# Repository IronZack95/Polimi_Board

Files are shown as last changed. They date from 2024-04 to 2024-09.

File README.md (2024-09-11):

# Polimi_Board
Design of new board for **Politecnico di Milano** Univeristy. \
This project is for the Embedded Systems course.
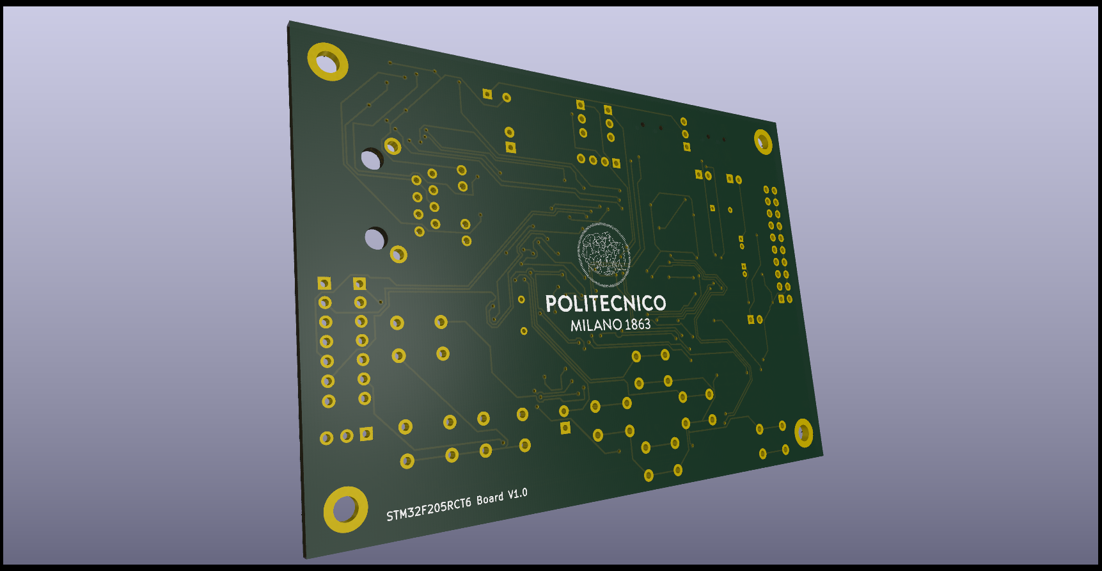
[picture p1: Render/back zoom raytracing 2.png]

## Description
The board is based on *STM32* chip - **[STM32F205RCT6](https://www.st.com/resource/en/datasheet/stm32f205rb.pdf)** as a main core.
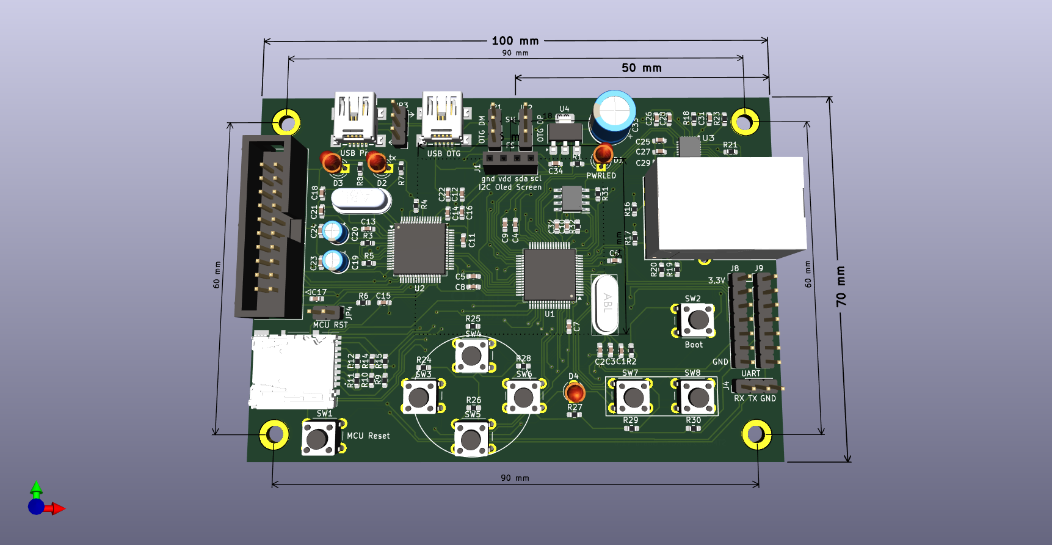
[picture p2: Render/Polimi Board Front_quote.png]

# Board Design specifications
- [x] 1x [specific main core chip](https://estore.st.com/en/stm32f205rct6-cpn.html)
- [x] 1x micro-USB B Port, directly connencted to the main chip.
- [x] 1x micro-USB B Port, for serial progeamming chip **FT2232**
- [x] 1x micro-SD Port, With SDIO/MMC protocol
- [x] 1x Ethernet Port, with magnetic transformer included, wired to **LAN8742** chip
- [x] 1x reset button
- [x] 6x General buttons, 4 of them placed as a joystick cross, the others beside
- [x] 1x power LED
- [x] 1x JTAG interface
- [x] 1x LED linked to a GPIO Port
- [x] 1x [OLED SCREEN I2C AMAZON](https://www.amazon.it/AZDelivery-Display-retroilluminato-Raspberry-gratuito/dp/B078J78R45?ref_=ast_sto_dp&th=1), or [OLED SCREEN I2C AZ-DELIVERY](https://www.az-delivery.de/it/products/1-3zoll-i2c-oled-display)
- [x] 1x External Flash SPI chip

# Notes
- Jumpers are introduced to choose the direction of the USB OTG, in one case HS (High speed) and in one case FS (Full speed)
- Jumpers are introduced to choose power from USB OTG and USB Programming
- The primary source of power arrives from USB
- Board size **10cm x 7cm**
- Hole distances **6cm x 9cm**

## BOM - Mouser
https://www.mouser.it/api/CrossDomain/GetContext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

# Potential problems
- cambiati i simboli dei connettori RJ45, micro SD e mini USB
- la micro SD non ha l'uscita WRITE PROTECT, è un problema? è stata scollegata 
- microSD card detect è stato messo in corrispondenza di PC6 -> SDIO_D6

# To be reviwed
 - [x] La footprint del cristallo da 25 MHz è sbagliata, la distanza tra i pin è 4.15mm invece che 4.88. Dovrebbe essere uguale a quella del cristallo da 12 MHz che invece è giusta.
- [x] Puoi togliere dalla BOM l'STM32 perché li abbiamo già in abbondanza
- [x] Per i led si può scendere col prezzo: ad esempio un led verde da 0.15$ invece che 0.3: https://www.mouser.it/ProductDetail/Wurth-Elektronik/151031VS06000?qs=LlUlMxKIyB01ggED1iKswA%3D%3D
- [x] Idem per i condensatori; questi da 100nF (0.1uF) costano solo 0.093€ l'uno: https://www.mouser.it/ProductDetail/KYOCERA-AVX/06033G104ZAT2A?qs=NXubJDmysXJMPmHfVo6Z%252BA%3D%3D
Ricorda di ordinare per prezzo (e filtra solo per i componenti in stock al momento) quando cerchi i componenti e specialmente per i passivi prendi sempre le cose meno costose (finchè sono in specifica per quanto riguarda voltaggio (potenza per le resistenze) e valore del componente).
In generale tutti i passivi mi sembrano più costosi del necessario.
- [x] Condensatore da 47uF: hai scelto un condensatore ai polimeri, costano ma a parte che non hanno la tendenza di sputare fuori l'elettrolita hanno caratteristiche generalmente *peggiori* dei condensatori elettrolitici normali. Per gli elettrolitici è preferibile prendere quelli through hole "vecchio stile", con una tensione di lavoro/temperatura massima sovradimensionata. Per esempio questi condensatori da 47uF della Panasonic https://www.mouser.it/ProductDetail/Panasonic/EEU-EB1J470S?qs=ctSfcQVnnmTBOdyC1HlWZw%3D%3D non costano nulla (0.26€ cadauno) e hanno una durata di esercizio di ben 5000 ore e una tensione max di lavoro di 63V e una temperatura massima di 105°C. Nella nostra applicazione è perfettamente equivalente al condensatore ai polimeri (anzi l'unica differenza sostanziale è che il condensatore ai polimeri andava fino a 100V, cosa che non ci serve) ma costa 1/10 del prezzo.
- [x] i chip vanno bene, i connettori vanno bene, riguarda tutti i passivi e cerca di scendere coi prezzi. Ho guardato principalmente i condensatori ma non escludo che si possa scendere di prezzo anche con le resistenze.
- [x] Mi sembra che manca il connettore IDC per il JTAG e le strip da 2.54mm per jumper e breakout vari. Il connettore IDC lo possiamo lasciare fuori dalla BOM perché non credo ci servirà e i connettori costano.
- [x] Per le strip da 2.54mm ti consiglio questa serie: https://www.mouser.it/c/?tradename=EconoStik Attenzione a selezionare nel filtro le seguenti proprietà, altrimenti le misure del connettore saranno sbagliate:
- Termination Post Length: 3.05mm
- Mating Post Length: 5.84mm

Commenti vari sul layout:
- [x] I connettori USB posizionali bene in modo che l'estremità del connettore (quella suggerita dal silkscreen) arrivi a toccare il bordo della scheda, altrimenti non sarà possibile infilare la spina nel connettore senza che il corpo della spina ostruisca l'inserimento.
- [x] Idem come sopra per il connettore Ethernet. Le sagome di ingombro della libreria di KiCad (quelle che compaiono col bordo rosa) sono estremamente conservative; non farti problemi a farle intersecare un po' se lo ritieni necessario.
- [x] Le dimensioni della scheda sembrano un po' abbondanti, magari si può scorciare un pochino verticalmente (tipo 60mmx100mm invece che 100x100)

## Usefull Links
- [Big Board reference with Ram](https://github.com/HEAPLab/marco-ram-board/tree/master)
- [Thermal camera project](https://github.com/fedetft/thermal_camera)
- [How to connect micro SD](https://emanbuc.gitbooks.io/appunti-iot/content/manuscript/sd_card_connection.html)
- [Oled alternatives](https://www.az-delivery.de/it/products/0-96zolldisplay), or [like](https://www.ebay.it/itm/204428760352?itmmeta=01HQXT2FC1579AP9QA0BS3KWXZ&hash=item2f98e75520:g:HqMAAOSw8oZhO3MO) (NOT USED!!)

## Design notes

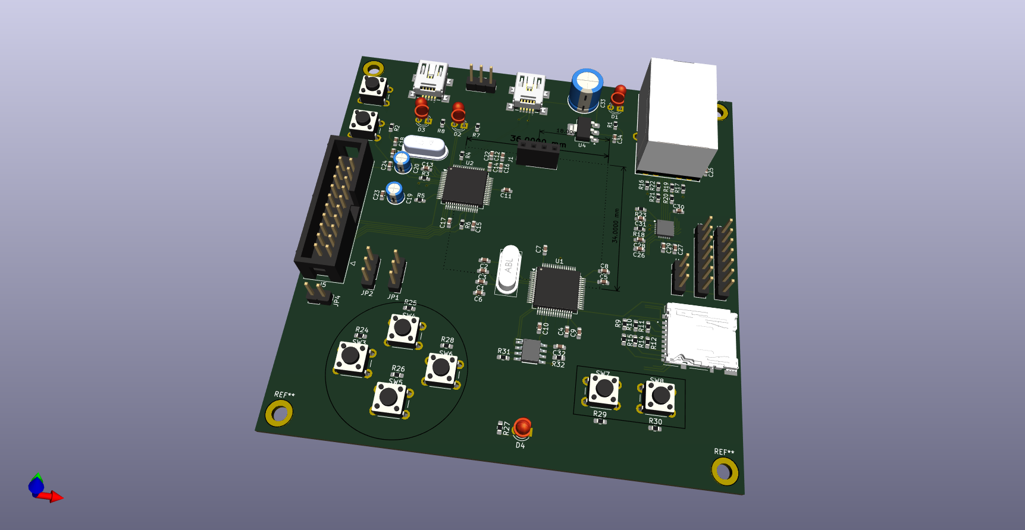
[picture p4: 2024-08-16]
Polimi Board.png

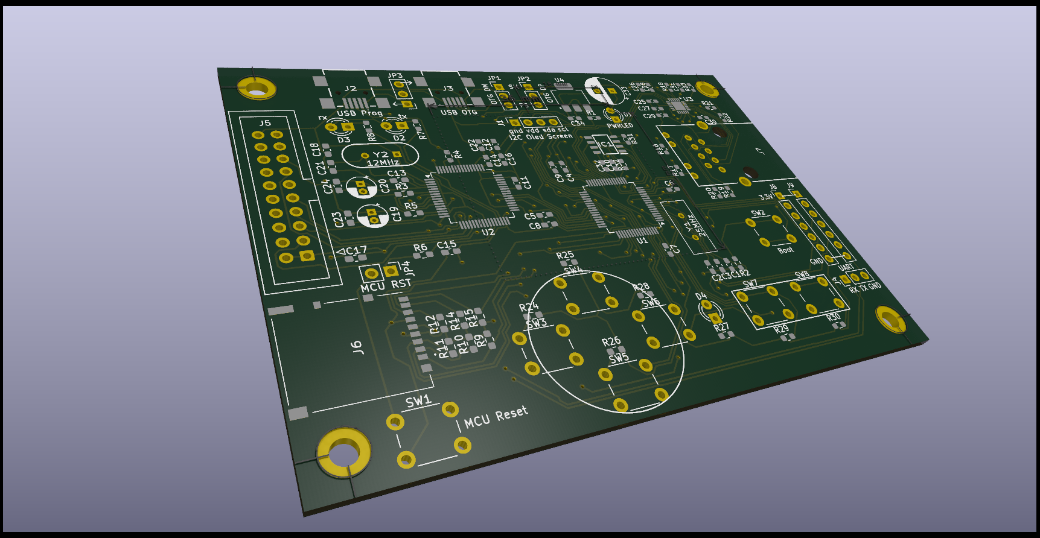
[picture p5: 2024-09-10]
Render/front raytracing 2.png

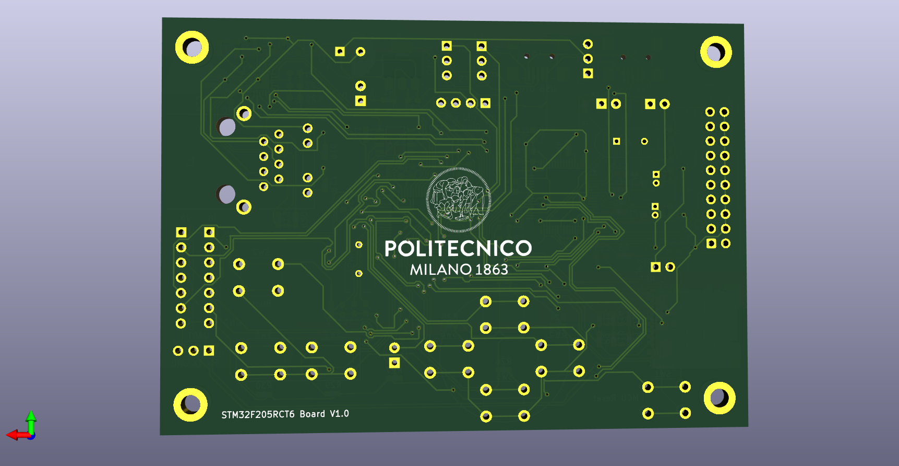
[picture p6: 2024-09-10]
Render/Polimi Board Back.png

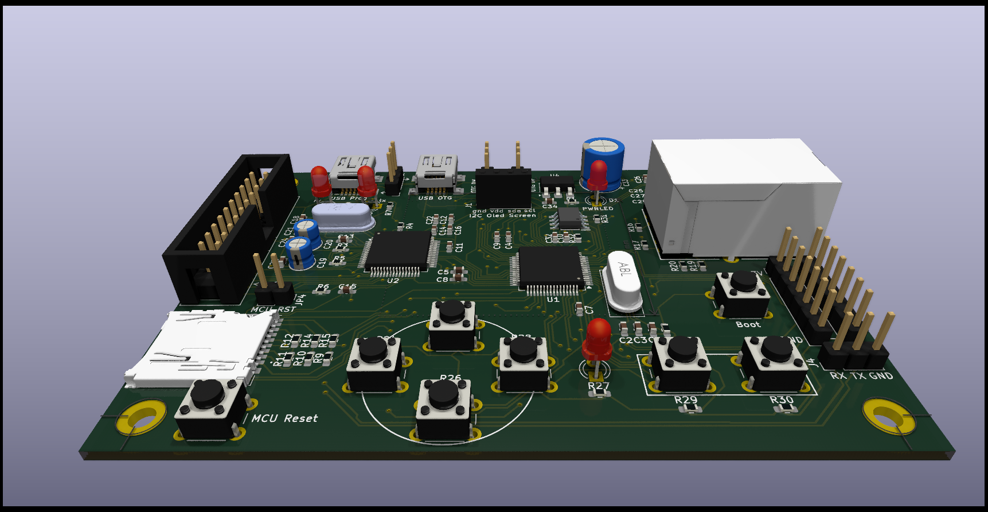
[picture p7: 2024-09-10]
Render/front raytracing.png

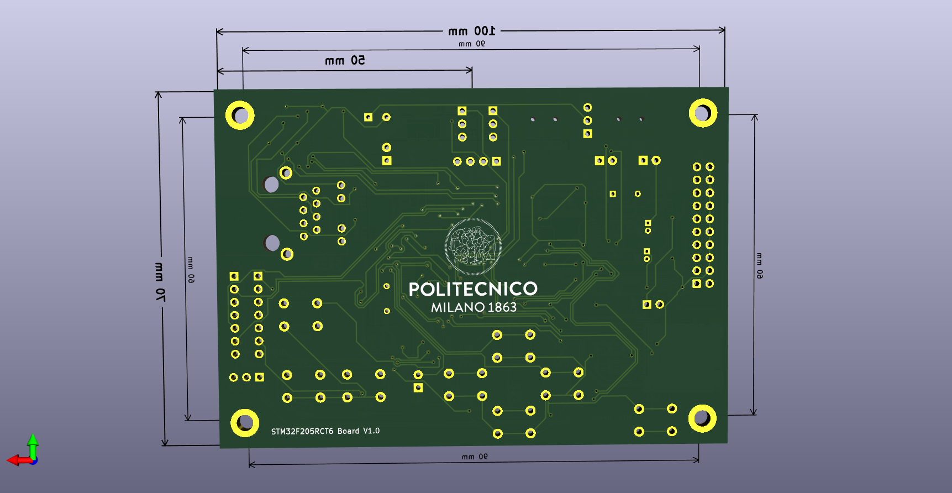
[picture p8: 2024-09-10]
Render/Polimi Board Back_quote.png

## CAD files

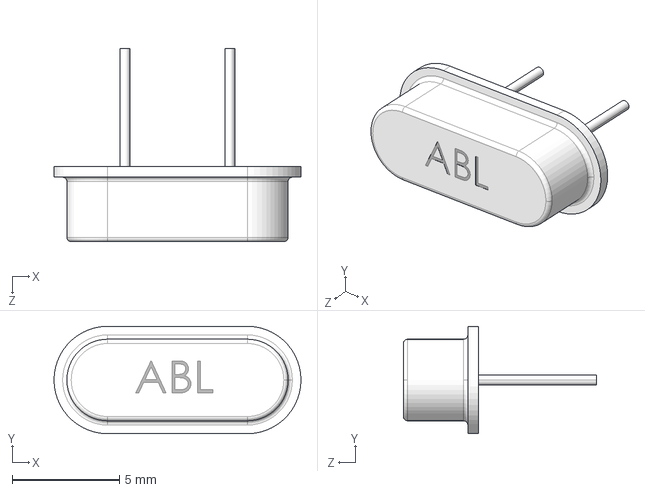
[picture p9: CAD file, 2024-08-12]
Imported/LIB_ABL-25.000MHz-B1UB/ABL-25.000MHz-B1UB/3D/ABL-25.000MHz-B1UB.stp
11.5 x 5.00 x 9.00 mm

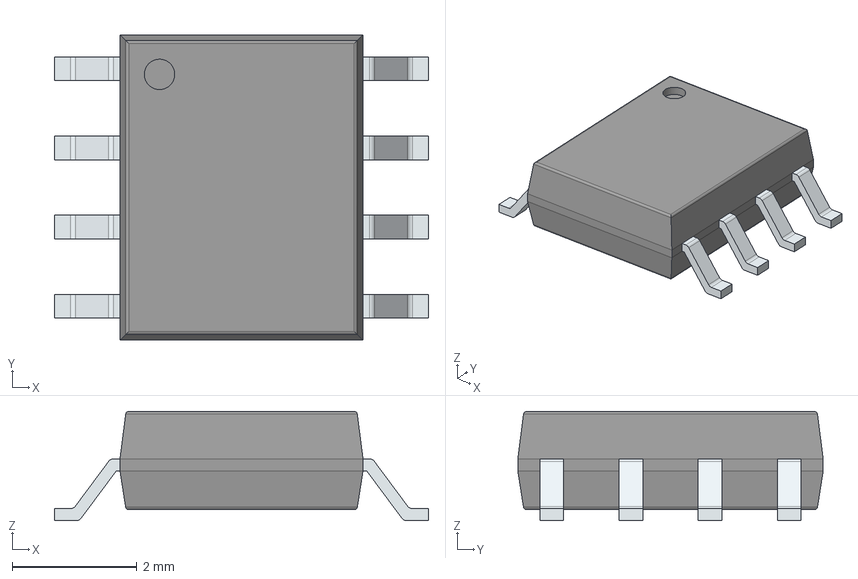
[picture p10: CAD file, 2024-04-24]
Imported/LIB_M95512-RMN6P/M95512-RMN6P/3D/M95512-RMN6P.stp
6.00 x 4.90 x 1.75 mm
PinsArrayLR

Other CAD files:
Imported/LIB_ABL-25.000MHz-B1UB/ABL-25.000MHz-B1UB/Allegro/abl25000mhzb1ub.psm
Imported/LIB_ABL-25.000MHz-B1UB/ABL-25.000MHz-B1UB/DEHDL/abl_25.000mhz_b1ub/chips/chips.prt
Imported/LIB_M95512-RMN6P/M95512-RMN6P/Allegro/soic127p600x175-8n.psm
Imported/LIB_M95512-RMN6P/M95512-RMN6P/DEHDL/m95512_rmn6p/chips/chips.prt

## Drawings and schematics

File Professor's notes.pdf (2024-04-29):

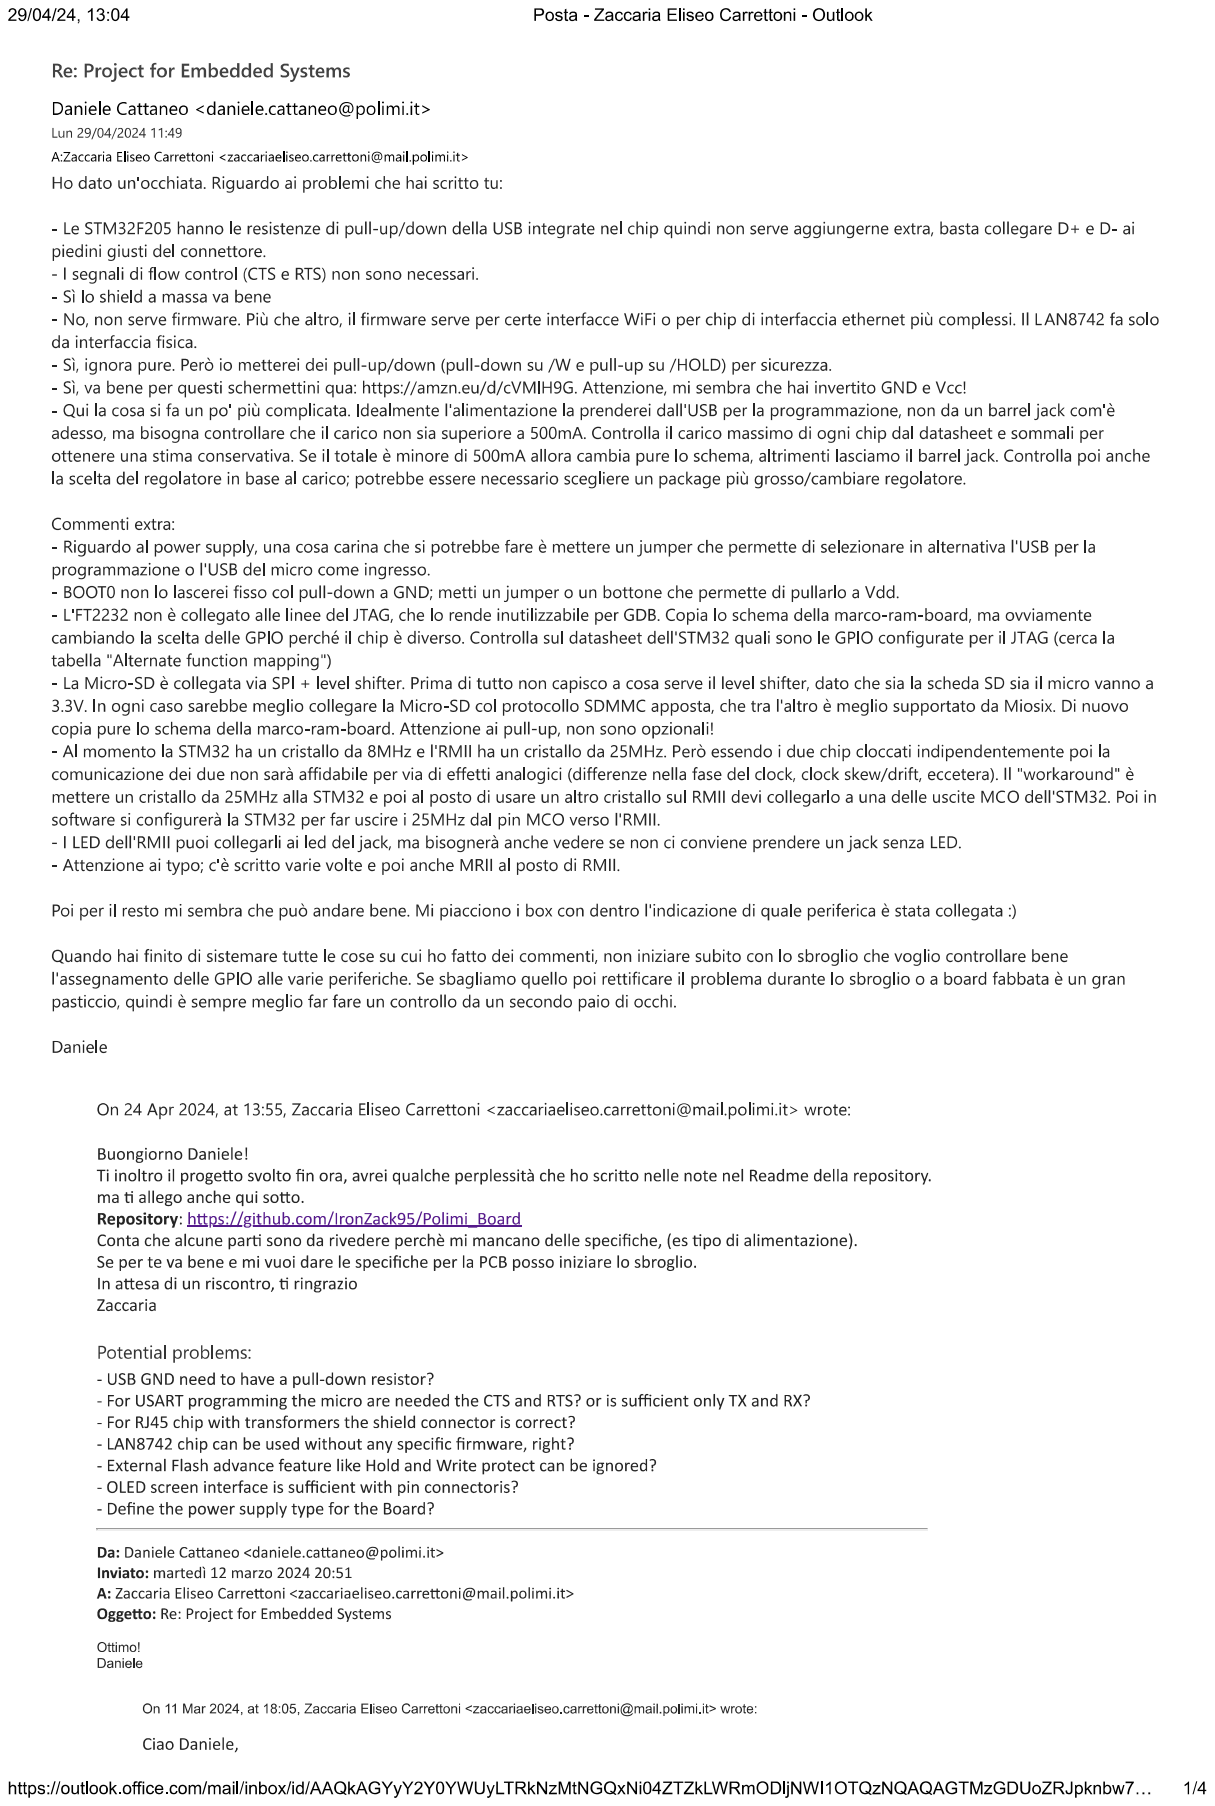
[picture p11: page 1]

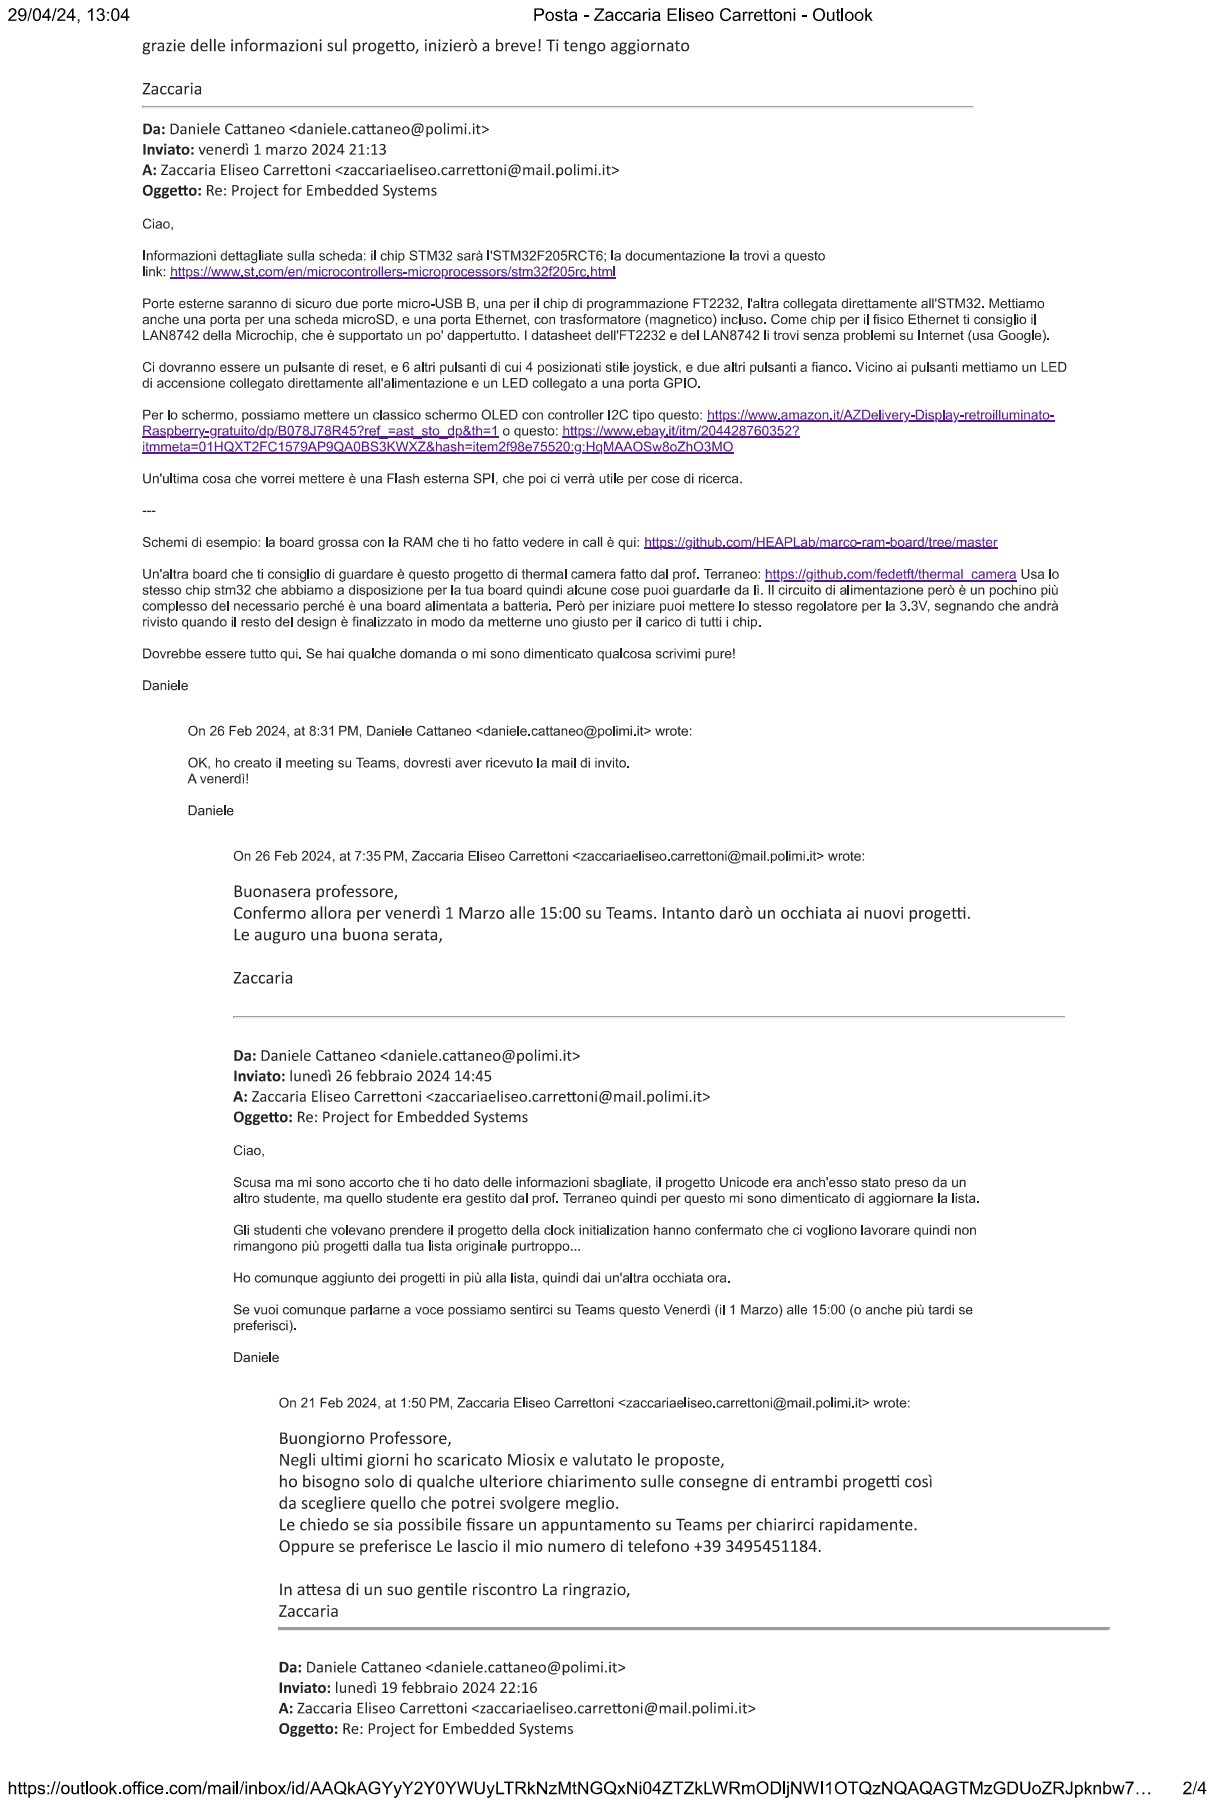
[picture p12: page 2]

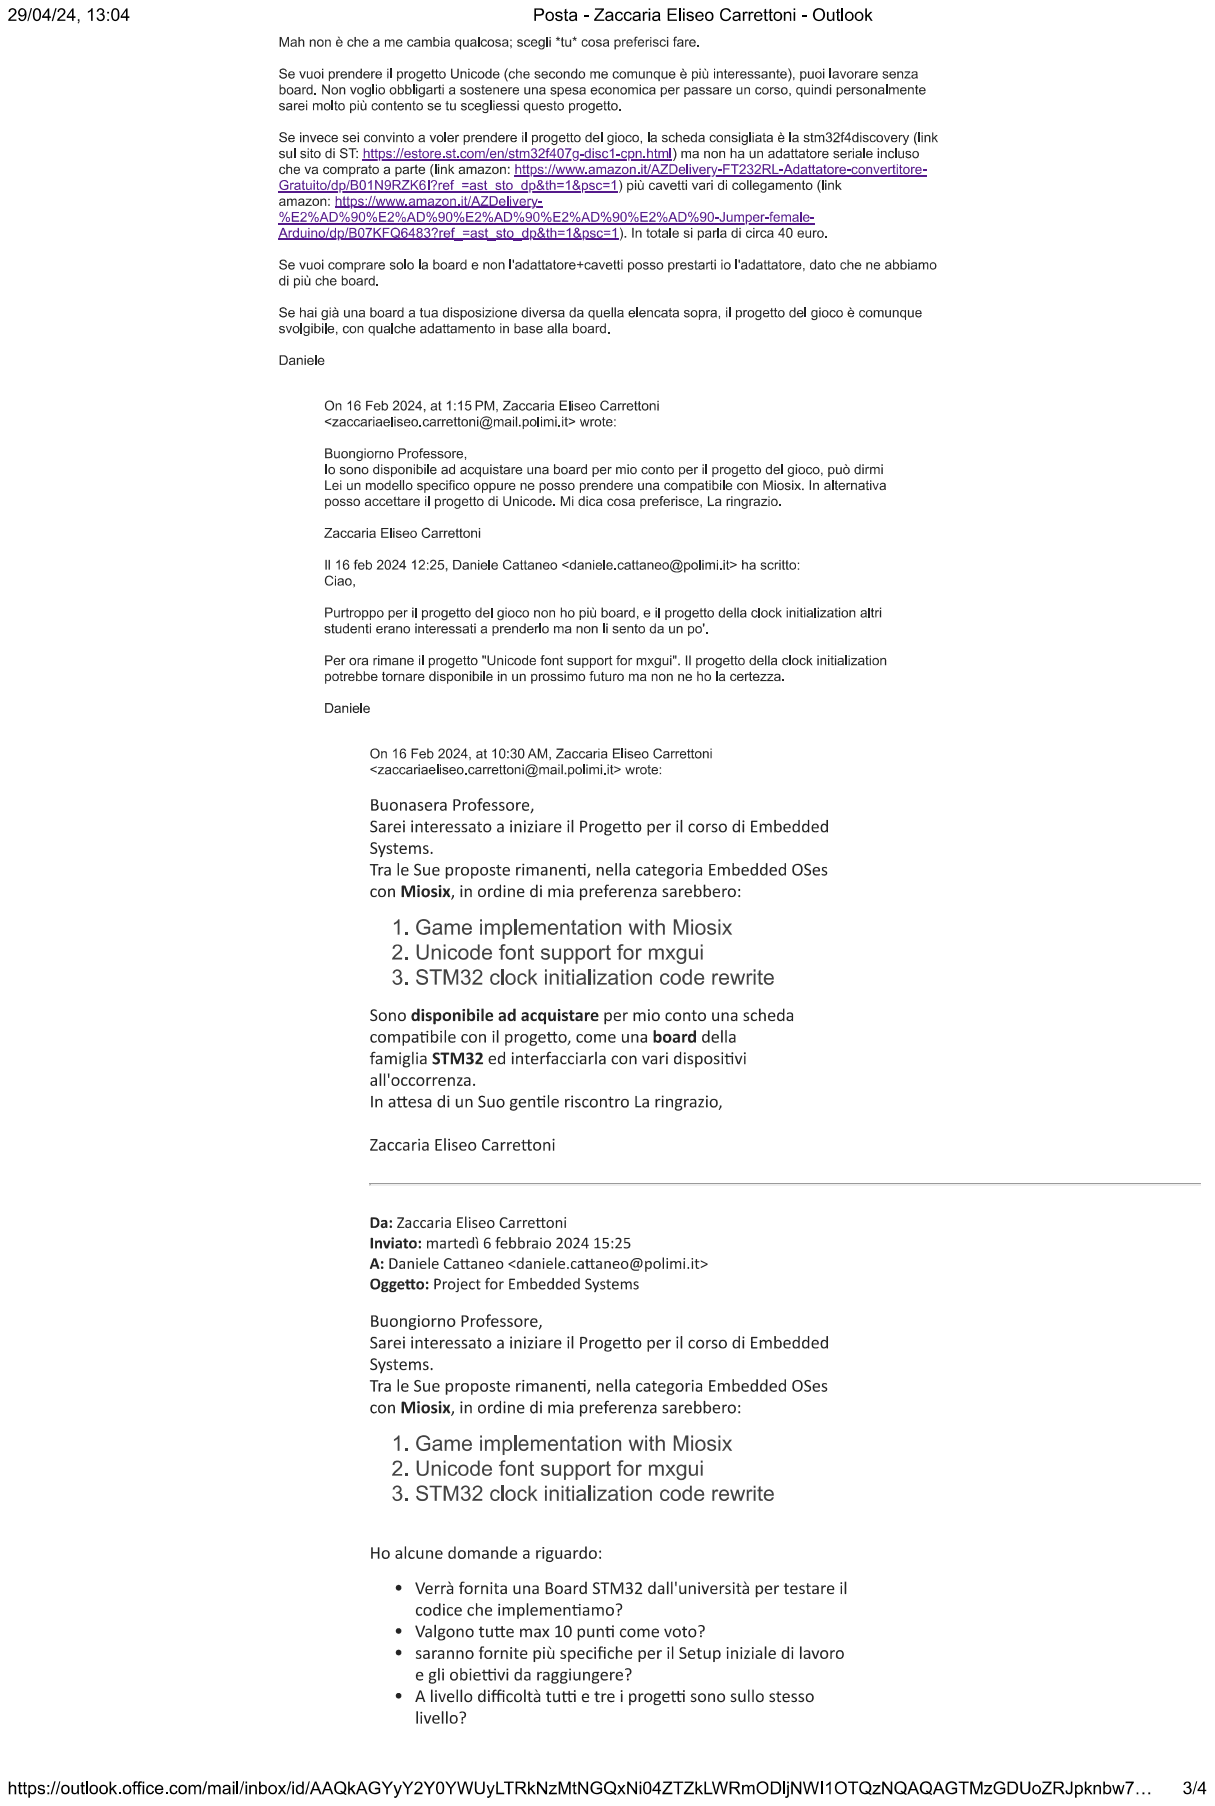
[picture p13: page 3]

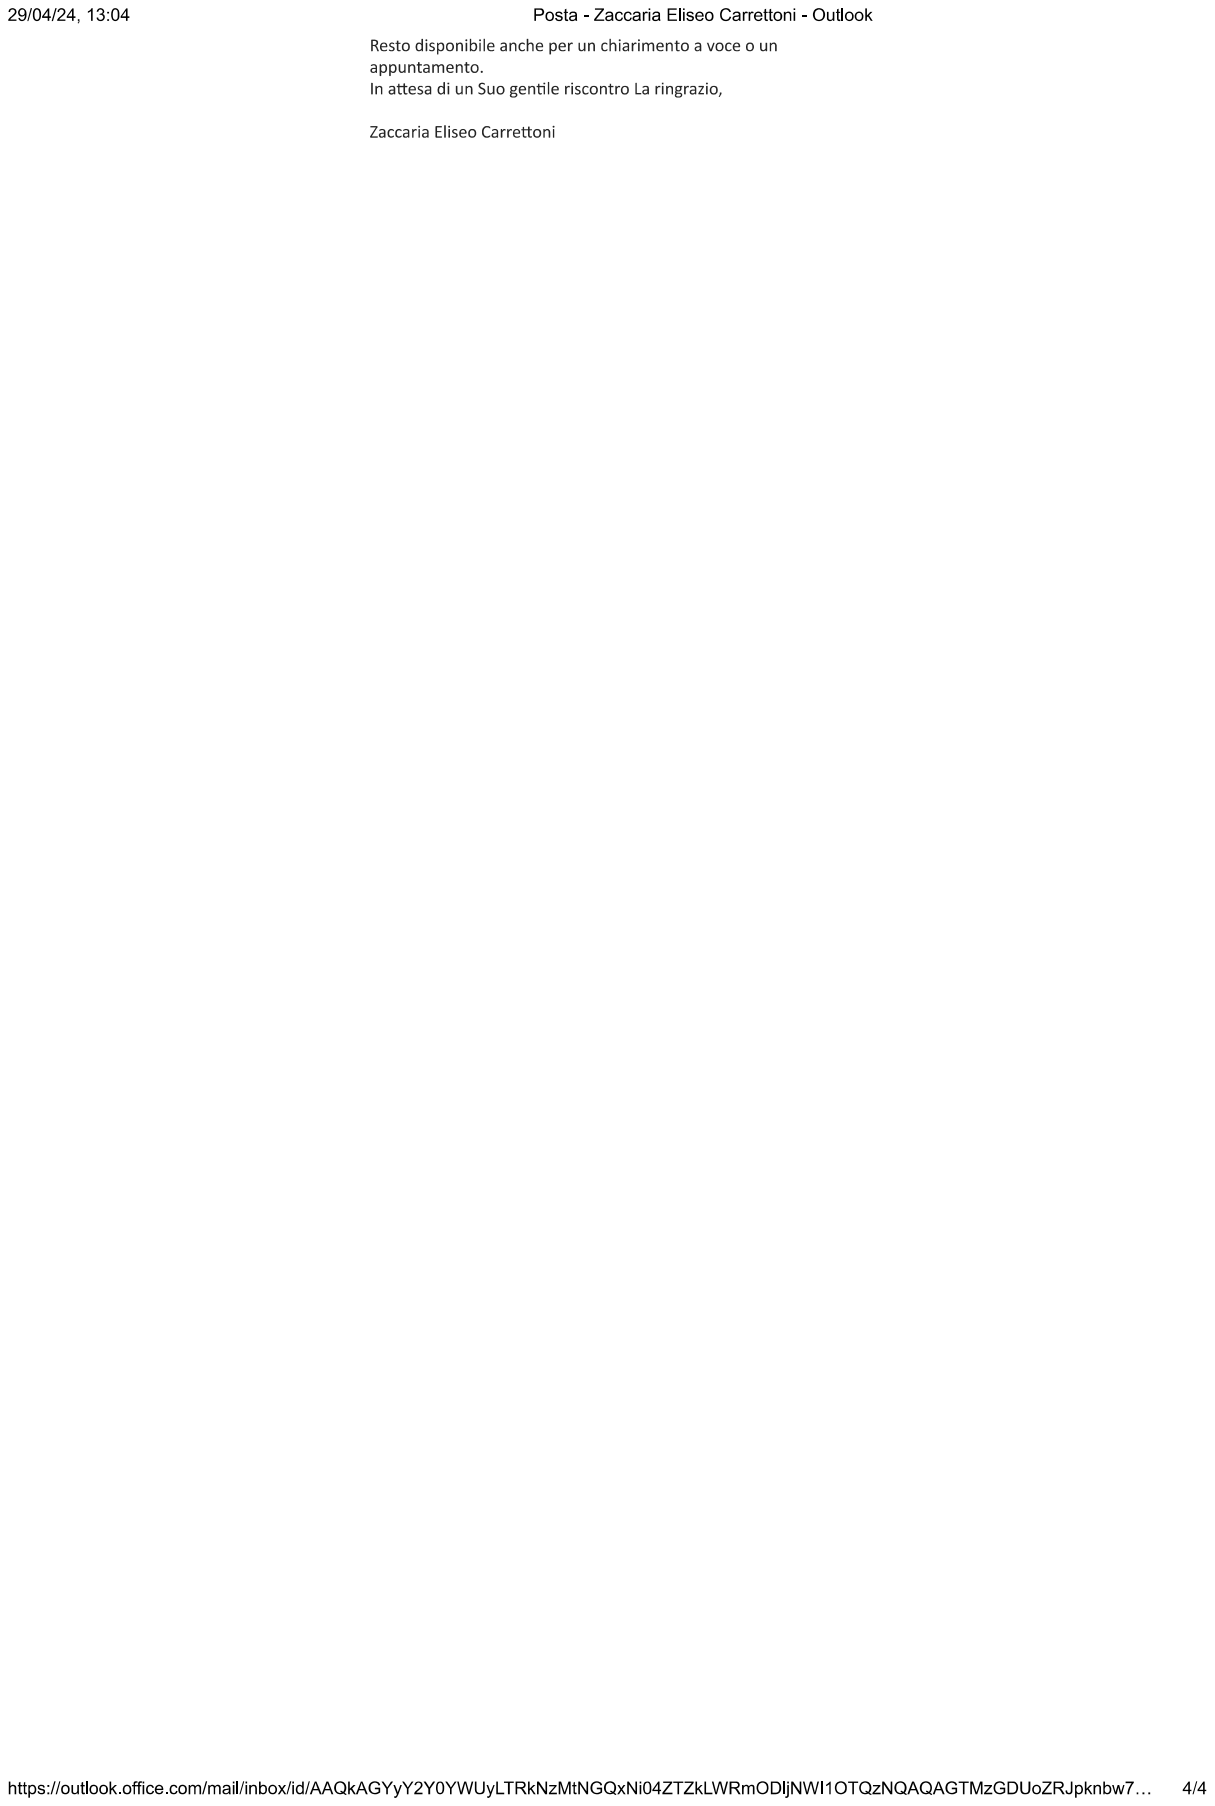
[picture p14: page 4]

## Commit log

2024-03-24 Polimi Board
    [EDI2CAP.CFG, Oled_Screen.kicad_sch, Polimi Board.kicad_pcb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]
2024-04-09 added programming oled and SD
    [Ethernet.kicad_sch, Micro_SD.kicad_sch, Oled_Screen.kicad_sch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]
2024-04-12 Added GPIOs
    [Ethernet.kicad_sch, GPIO.kicad_sch, Micro_SD.kicad_sch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]
2024-04-24 Finish schematic part
    To be reviewd
    [EDI2CAP.CFG, Ethernet.kicad_sch, GPIO.kicad_sch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]
2024-04-29 Fatte modifiche
    [Ethernet.kicad_sch, GPIO.kicad_sch, Micro_SD.kicad_sch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]
2024-05-14 Update the design with new specifications
    [Ethernet.kicad_sch, GPIO.kicad_sch, Micro_SD.kicad_sch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]
2024-05-15 Update resets and readme
    [Ethernet.kicad_sch, GPIO.kicad_sch, Micro_SD.kicad_sch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]
2024-05-15 Adjusted Leds
    [Ethernet.kicad_sch]
2024-07-16 Added changes to the design
    Ready for pcb design
    [Ethernet.kicad_sch, GPIO.kicad_sch, Micro_SD.kicad_sch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]
2024-07-16 adjusted some violations of ERC test
    [Ethernet.kicad_sch, Polimi Board.kicad_sch, Power.kicad_sch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]
2024-08-12 Added footprint from Mouser
    readu for wiring
    [ABL-25.000MHz-B1UB.stp, EDI2CAP.CFG, Ethernet.kicad_sch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]
2024-08-16 PCB wip
    before holidays
    [Ethernet.kicad_sch, GPIO.kicad_sch, Micro_SD.kicad_sch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]
2024-09-09 almost finish
    [Polimi Board.kicad_pcb]
2024-09-10 Final version
    [Polimi Board.kicad_pcb]
2024-09-10 Set zero at top left corner of PCB
    [Polimi Board.kicad_pcb]
2024-09-11 Solved issues
    3.3V 3V3 and others
    [Ethernet.kicad_sch, GPIO.kicad_sch, Micro_SD.kicad_sch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]
2024-09-23 Solved filled zones
    [Polimi Board.kicad_pcb]
